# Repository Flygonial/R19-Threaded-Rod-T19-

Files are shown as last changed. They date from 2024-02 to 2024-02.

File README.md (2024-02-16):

# R19-Threaded-Rod-T19-

The repository for all the source files, code, and .stls for my threaded rod derivative of the T19, the R19. Held together with three 1' 8-32 threaded rods, and assorted 6-32 bolts (you also can use M3, but it is a bit hacky), and also aesthetically distinct. The cage has been changed to feature a threaded rod adapter (recommend 100% infill) and space for a rod overhead, the magwell has been adapted to accept these same rods and had its controller covers redesigned, and the rear end has been entirely remodeled (but still adhering to the original blaster's design language). 

Designed for a generic Amazon 40x60mm [perfboard](https://www.amazon.com/ELEGOO-Prototype-Soldering-Compatible-Arduino/dp/B072Z7Y19F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), the rear end of the blaster has been narrowed to more closely adhere to the stepper's profile. Ironically, this does slash half-length compatibility since that variant of the T19 kept its ESCs in the Drive Housing. I bought my own Arduino Pro Minis and DRV8855 boards and followed Toruk's [detailed but somewhat outdated guide](https://torukmakto4.blogspot.com/2019/01/t19-build-guide-part-7-blaster.html). Do note that pins 2 & 3 were reassigned to the tachometer lines [which need to be exposed from under your ESC's shrink wrap and hot-wired to](https://torukmakto4.blogspot.com/2021/01/flashing-ztw-spiders-for-flyshot.html), and correspond to now separate throttle lines for each ESC (10 & 2 and 9 & 3 respectively). As far as pin changes, note that I ended up reassigning the STEP pin off the DRV8855 to A0 (D14) and its DIR pin to A1 (D15). As the trigger lines follow the original guide (at 11 & 12), those were changed as well. I changed register accesses to correspond to these as well, which are documented in my code.

* D11: PORTB 00001000 - Trigger line 1
* D12: PORTB 00010000 - Trigger line 2
* D14: PORTC 00000001 - STEP signal
* D15: PORTC 00000010 - DIR signal

All code related to driving select-fire or speed/ROF setting were commented out. Implementing an old-styled hold down trigger on boot to set velocity and/or a tournament lock wire are things I'm interested in but that's the way it is now. If working from the original T19 source, or using mine, do be a bit more careful than me and not change/comment out things you actually needed. Bregg's [fork](https://github.com/MatthewBregg/SimpleT19Code) may be more useful for you if you want to work from scratch with your own hand-wired board and pinouts, and if you don't plan on implementing on-the-fly velocity and ROF tuning or select-fire.

To assemble the stock, keep in mind that you will need to cut 1/2"x1/8" aluminum flatbar to 200mm, trace out the drill holes (insert into the stock and mark drill points), and then cut out the locking points yourself. These can be configured to your liking, but I don't recommend making any points beyond about 150mm (which is already about 12" LOP) down as there will no longer be adequate support for bar contact to the stock. For each slot, measure out about 6mm in length for a slot and use a triangular file to open up each side and a flat file (with its thinner side) to finish it off. You can get away with as little as about 3mm deep, just don't make it too deep and compromise the flatbar's structural integrity. The locking pin is held in place by a piece on the end of the stock and needs its own spring.

I used the eBay Helibatics F-30A (originally Hobbyking) clones for 30A SimonK ESCs. I'm not positive this will be a reliable source forever (probably not), but the seller is a responsive, nice guy who has a big stockpile of them, and these ESCs are known to be fairly fuss-free for being flashed with FlyShot. I used the Arduino method in MBregg's earlier linked post, where I used KKMultiCopter, picked arduinosblinker inside the software, hooked my ESC up to a power supply (NiMH pack, Lipo, anything with enough voltage and some baselin of current capability works), and flashed Toruk's pre-compiled bs_nfet.hex file. Without buying an extra tool or needing to deal with Windows' shoddy USB driver compatibility, this worked and all I needed to do was install Java (and promptly uninstall it afterward).

With all this being said and done, keep in mind that this is primarily meant as a one-off build for myself. It has hacky, janky bits and will not be well-documented. Additional desired features, like short support, select-fire support, etc., are not likely to be implemented unless I want them for myself. I am open to answering questions on snags I faced and how these can be addressed, but no promises.`

# Licensed under the Creative Commons BY-SA 4.0 license
Inherited from the license of the T19, developed by torukmakto4. Information here: https://creativecommons.org/licenses/by-sa/4.0/

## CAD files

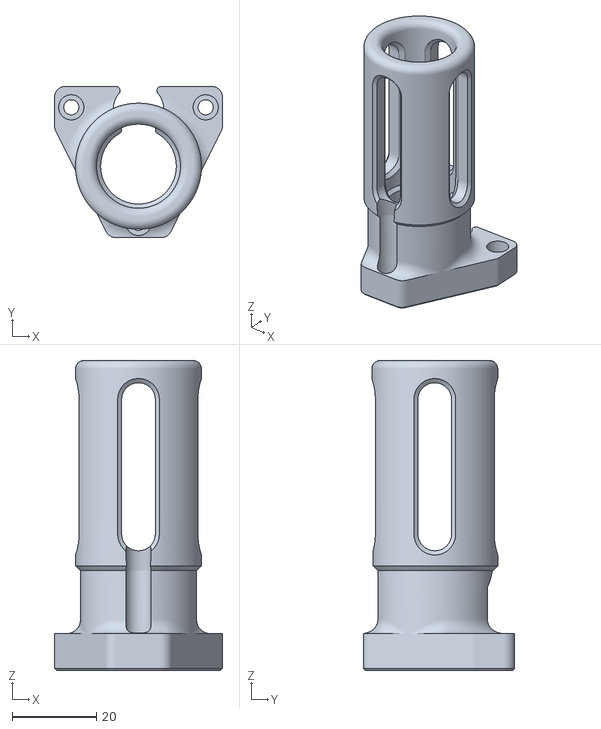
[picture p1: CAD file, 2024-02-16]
Cage/R19 Flash Hider.stl
40.0 x 36.0 x 73.8

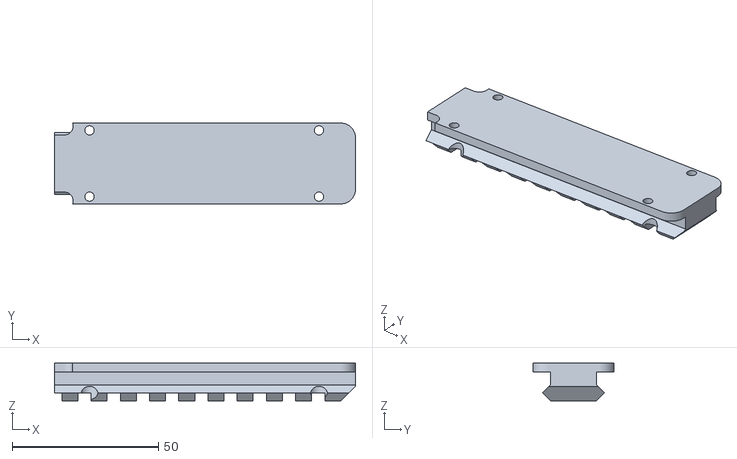
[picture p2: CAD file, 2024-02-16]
Drive/R19 Drive Rail.stl
103.0 x 27.7 x 13.0

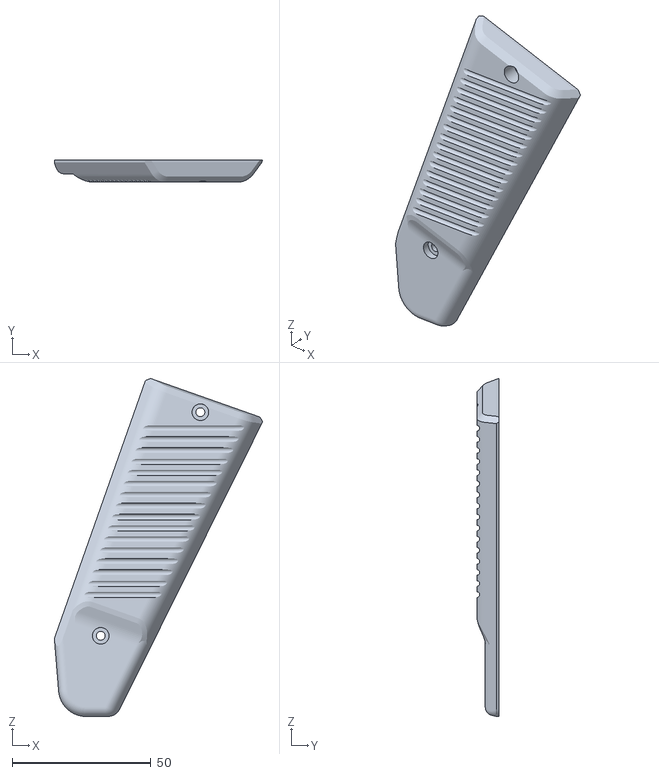
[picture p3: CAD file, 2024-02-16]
Grip/Right Grip Panel.stl
75.1 x 8.00 x 121.9

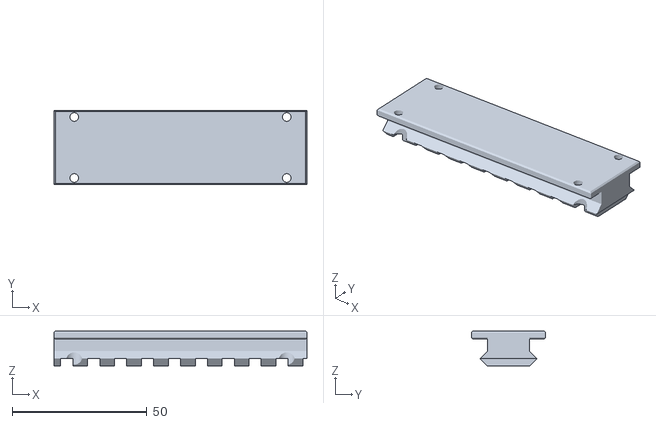
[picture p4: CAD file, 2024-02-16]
Magwell/R19 FL Rail.stl
94.0 x 27.7 x 13.0

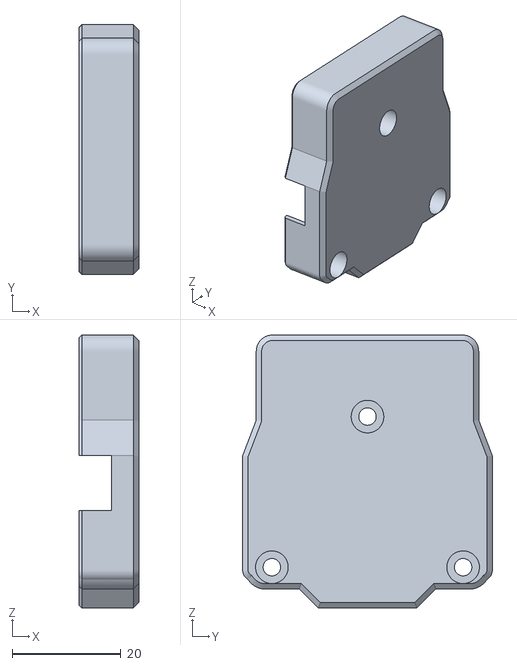
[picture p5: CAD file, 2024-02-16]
Stock/Locking Pin Cover.stl
11.0 x 45.9 x 50.2

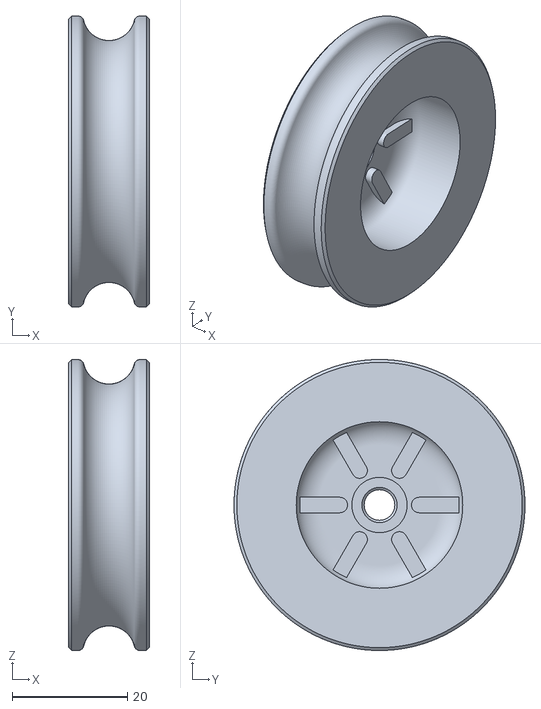
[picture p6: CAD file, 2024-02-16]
Cage/Hy-Con_Wheels_iFlight_XE_2207_PRO_9.5mm.stl
14.0 x 50.5 x 50.5

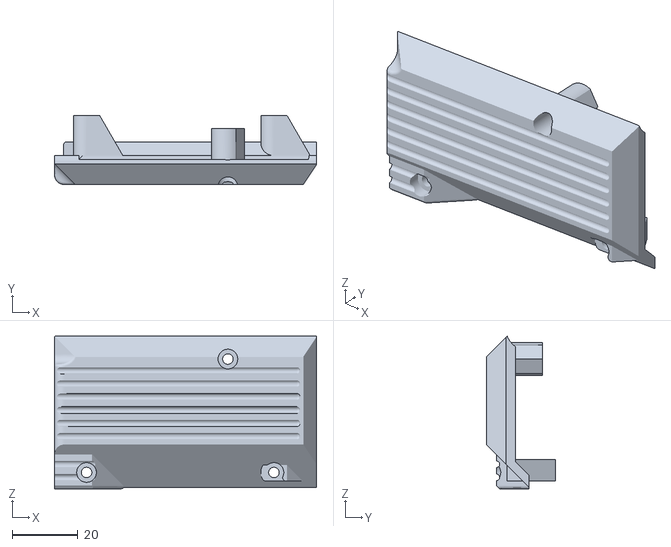
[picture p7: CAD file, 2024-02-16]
Magwell/R19 Right Controller Cover.stl
79.7 x 21.0 x 46.5

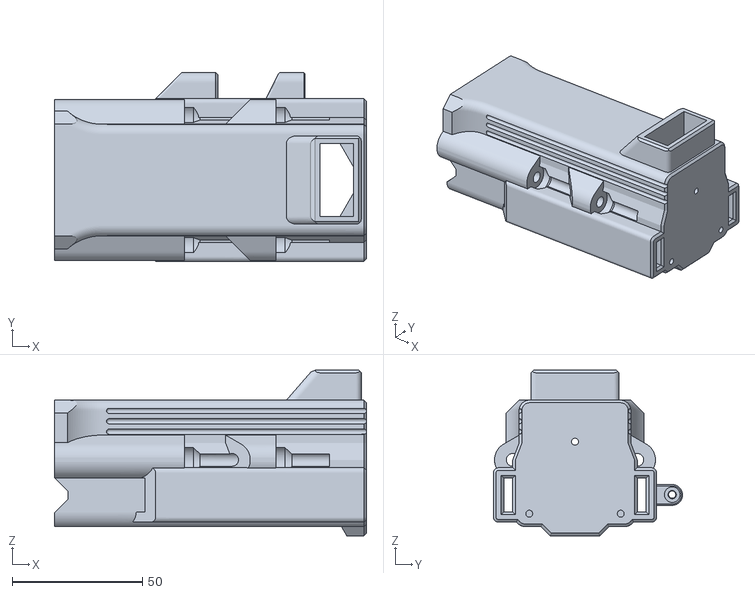
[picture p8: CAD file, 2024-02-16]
Stock/R19 Battery Stock.stl
120.0 x 72.8 x 63.7

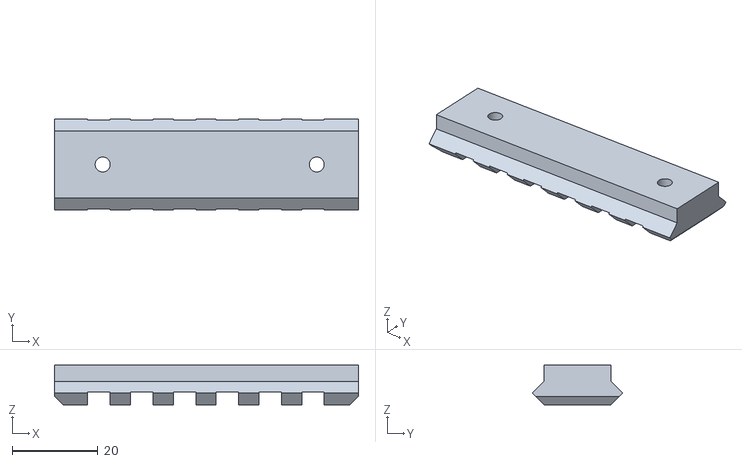
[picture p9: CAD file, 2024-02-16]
Cage/T19DeltaSideRail.stl
71.0 x 21.2 x 9.32

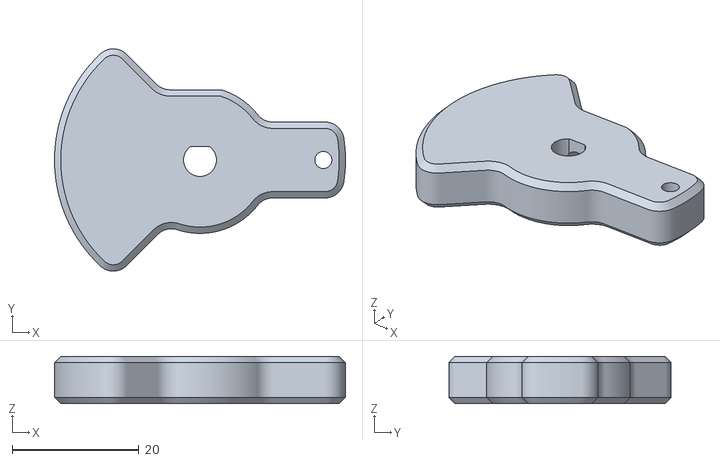
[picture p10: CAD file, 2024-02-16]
Drive/R19 Crank.stl
46.0 x 35.1 x 7.50

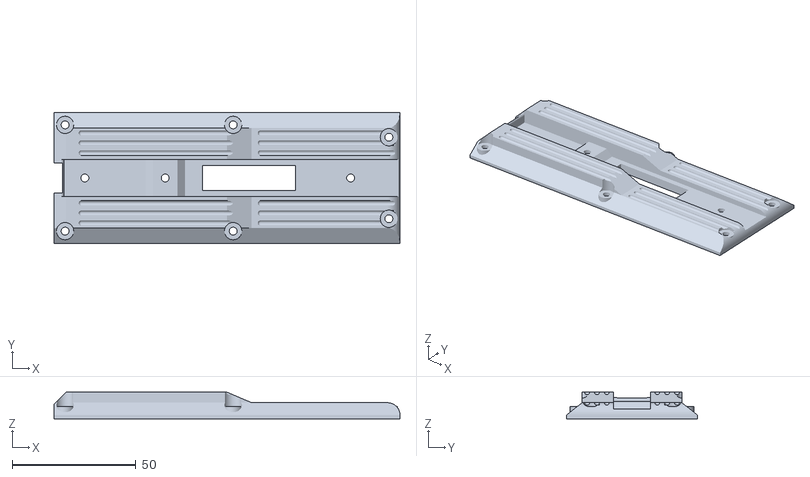
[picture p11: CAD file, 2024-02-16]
Grip/Grip Plate.stl
140.0 x 53.0 x 10.8

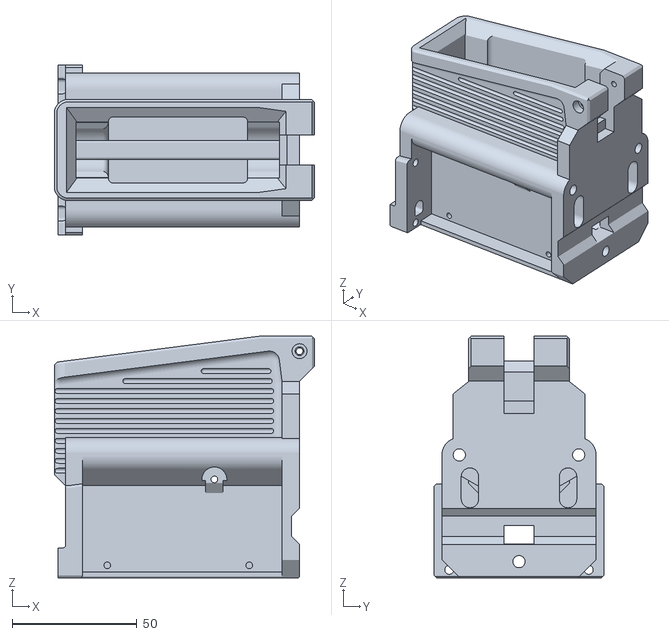
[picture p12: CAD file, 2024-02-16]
Magwell/R19 Magwell.stl
104.4 x 68.4 x 97.0

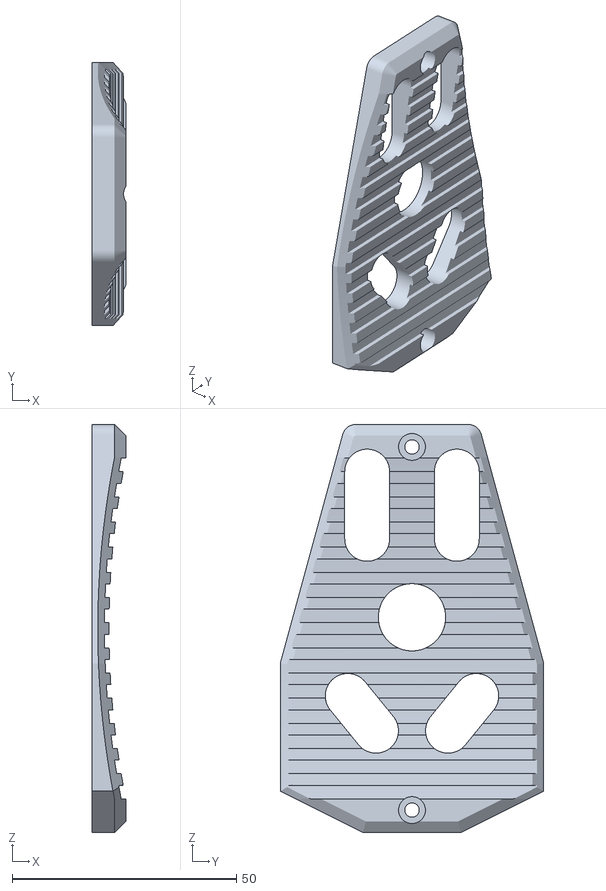
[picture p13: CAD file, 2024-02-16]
Stock/R19 Stock Pad.stl
7.50 x 58.8 x 91.0

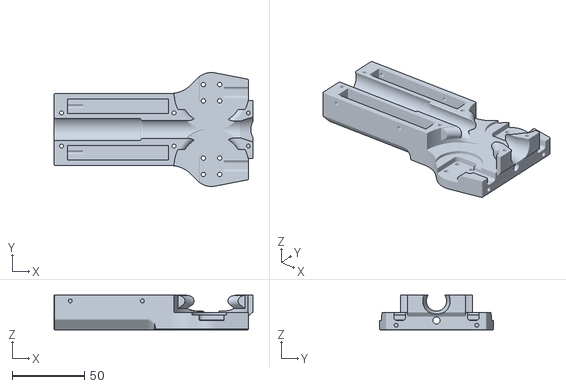
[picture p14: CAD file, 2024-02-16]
Cage/R19 9.0 Hy-Con Delta Cage.stl
138.0 x 79.0 x 24.0

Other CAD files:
Grip/Left Grip Panel.stl
Drive/R19 Drive Housing.stl
Grip/R19 Grip Frame.stl
Magwell/R19 2Way Release.stl
Cage/Hy-Con_Wheels_iFlight_XE_2207_PRO_9.0mm.stl
Cage/HyCon Delta BR2207.stl
Cage/R19 Cage Adaptor.stl
Cage/R19 Delta Cage Rail.stl
Cage/R19 Underrail.stl
Cage/Side Rail Delete.stl
Drive/BoltBushing.stl
Drive/R19 Bolt.stl
Drive/R19 Drive Cover.stl
Drive/R19 Drive Spacer.stl
Grip/R19 Trigger Cover.stl
Grip/R19 Trigger.stl
Magwell/R19 Left Controller Cover.stl
Magwell/T19FLRelease.stl
Source/HyConiFlightXE2207PRO Source.f3d
Stock/Flatbar Locking Pin.stl
Stock/R19 Buttplate.stl
Stock/R19 Tray Door.stl

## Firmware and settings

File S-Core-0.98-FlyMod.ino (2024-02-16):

 ////S-Core Blaster Controller Firmware
 ////Version 0.98
 ////by torukmakto4
 ////DZ Industries
 ////This is part of Project T19
 ////Forever Open - Forever Independent
 ////Project T19 and this Software (DZ Core) are released under the Creative Commons BY-SA 4.0 license.
 ////https://creativecommons.org/licenses/by-sa/4.0/
 ////This is free and open source software.
 ////You may use or modify it for any purpose. No warranty or guarantee of fitness for any purpose is provided.
 ////It may be included in a product for sale, given that attribution is provided,
 ////and that if altered, the modified source is made publically available in a very clear manner.
 ////ANY DERIVATIVE OF THIS PRODUCT MUST BE PUBLISHED UNDER THE ORIGINAL LICENSE.
 ////No attempt to circumvent/thwart access or obfuscate its release by any technical measure may be made.
 ////In the end:
 ////Please arms race responsibly,
 ////don't be greedy,
 ////and respect the sporting spirit of our great hobby,
 ////above all else.
 ////DBAD.
 
 ////This targets:
 ////S-Core Single-Board Blaster Manager 1.0/1.5
 
 ////Flash this as (in Arduino IDE): Arduino Pro Mini 5V/16MHz.
 ////Use "Upload using programmer" (Shift-Upload) using a ISP tool and the 6-pin header on the S-Core board. Serial Bootloader flashing is NOT supported on S-Core.
 
 ////General blaster assumptions:
 ////200s/rev (100 pole) 2 phase hybrid stepper
 ////direct drive scotch yoke bolt, 1 shot per rev 
 ////SPST bolt limit switch
 ////SPDT trigger switch. Common to ground. Inputs are 1k pullup.
 ////Selector should be 3 position center off SPDT. Common to ground, position 1 and 2 to input lines (1k pullup)
 ////User Analog Input: Connect to wiper of a potentiometer, end terminals 5V and ground.
 ////SpeedLock input: This is a pot directly on the board.
 
 ////ATmega328P @ 16MHz with external ceramic resonator
 
 ////PINOUTS - S-Core 1.0/1.5
 //AVR pin - Arduino IDE pin - functionality
 //PC0 - D14 - Solenoid driver. Output. Active high. Pulldown (S-Core 1.0) - It is a GPIO pin on the 1.5.
 //PC1 - D15 or A1 (ADC capable) - Exposed on the GPIO connector for expansion or arbitrary use.

 // No selector switch on mine, remove and reassign:
 //PC2 - D16 - Selector input 2. Pullup.
 //PC3 - D17 - Selector input 1. Pullup.

 // Changed Stepper pins:
 // OLD:
  //PC4 - D18 - DRV8825 Step signal. Output. Rising edge triggered.
  //PC5 - D19 - DRV8825 Direction signal. Output.
 // NEW: PC0 and PC1
  //PC0 - D14 (A0) - DRV8825 Step signal, output, rising edge triggered.
  //PC1 - D15 (A1) - DRV8825 Direction signal. Output.

// This matches the original T19 wiring with the perfboard and uses the selector switch pins:
// NEW:
 //PB3 - D11 - Trigger input 1. Pullup.
 //PB4 - D12 - Trigger input 2. Pullup.
// OLD:
 //PD0 - D0 - Trigger input 1. Pullup.
 //PD1 - D1 - Trigger input 2. Pullup.

 //PD2 - D2 - INT0 - Tach input channel 0 (M1F). (Warning: These should NOT be allowed to float with the interrupt turned on if unused!!!!!!)
 //PD3 - D3 - INT1 - Tach input channel 1 (M2F).
 //PD4 - D4 - Bolt limit switch input. Pullup.
 //PD5 - D5 - DRV8825 M2. Output
 //PD6 - D6 - DRV8825 M1. Output
 //PD7 - D7 - DRV8825 M0. Output
 //PB2 - D10 - OCR1B - Throttle channel 0 (M1, M1F) associated with INT0 (PD2)
 //PB1 - D9 - OCR1A - Throttle channel 1 (M2, M2F) associated with INT1 (PD3)
 //PB0 - DRV8825 Enable. Output. Active low.
 //ADC6 - User analog input (KNOB)
 //ADC7 - Onboard analog input pot (SPL)
 
 //ICSP header:
 //PB3 - MOSI
 //PB4 - MISO
 //PB5 - SCK
 //PC6 - RESET (pullup)
 
 //PB6/PB7 - XTAL1/2 (Abracon Ceramic Resonator is present)
 
 //VCC = AVCC = AREF = 5V

 ////changelog of the NEW new era:
 ////08-19-19 - Rework for S-Core board, add dual-channel throttle and tach-based STC. Remove delay-based STC.
 ////08-31-19 - Implement digital governor updates, selective profile, analog speed inputs, ...
 ////12-30-19 - WIP Remove Alternate Mode. Analog knob is bolt speed control in run mode. Trigger down at boot to set speed.
 ////           Default to SPL setting. Throttle PWM interrupt to overlay governor updates instead of bitbang.
 ////           Add restart compensation to improve followup shot snappiness.
 ////           And then promptly comment out restart compensation. 
 ////02-09-20 - Fix all the wrong stuff with governor update interrupt management
 ////           Add ROF linearization, provision for configuring ROF in RPM, etc.
 ////           Start improving selftest
 ////02-14-20 - New hardware selftest, velocity watchdog, and fault codes
 ////02-29-20 - Rework selftest a bit to help bolt reset procedure spit out jam debris automatically with the flywheels and not create any new stoppage by feeding unknowingly while homing
 ////           Make Orthomatic feed control stricter and use a more appropriate polling period for checking tachs.
 ////04-07-20 - Fix erroneous trigger disconnection while full auto and decelerateBoltToSwitch(), etc.
 ////11-01-20 - Save user flywheel speed to EEPROM
 ////12-06-20 - Improve license statement clarity/intent (etc.)
 ////           Add quick "^beep^-_beep_" ("Old cellphone with dead battery") alarm feedback when a shot request
 ////           times out trying to reach set flywheel speed.
 ////           Disable tach interrupts as if the shot cycled when shutting down shots that timed out rather than erroneously leaving them on.
 ////           Make overspeed detect less strict (65 vs. 50) to prevent jumpy iflight cages from throwing errors.
 
 ////This uses the per-cycle lightweight calculation of stepper commutation period described in
 ////http://hwml.com/LeibRamp.pdf
 
#include <EEPROM.h>
 
////PWM Timer1 interrupt governor control variables
volatile int gov_currentBit;               //Loop counter/index (shall not be unsigned)
volatile unsigned long save_ocr1a;         //Save throttle settings to resume emitting them after all digital speed bits are shifted out
volatile unsigned long save_ocr1b;
volatile unsigned long governor;           //this has to be a volatile even though the ISR does not modify it
volatile boolean gov_enable_strobe = false; //Set to true to fire off update
volatile boolean gov_packet_active = false; //True while shifting bits out in the gov ISR, resets at the end of the cleanup cycle

int gov_update_repeats = 10;               //Number of min. times to repeat (Like Dshot commands, a one-time setting should be sent about 10 times to ensure noise robustness, etc.)

////FlyShot constant/setup section
volatile unsigned long gov_ocr_t0h = 26;   //T0H = 100us (Less than 250us)
volatile unsigned long gov_ocr_t1h = 90;   //T1H = 400us (More than 250 and less than MIN_RC_PULS)
//TL is by the PWM period. We will just keep running at 400Hz.
  
////tach variables - modified in tach ISRs
////tach pulse is counted on rising edge, once per AC cycle: 6*TIMING_MAX/4
////speed range should be something like 1200us - 330us for 7100 - 25900 motor rpm for reference
volatile unsigned long thisPulseTime0;
volatile unsigned long lastPulseTime0;
volatile unsigned long pulseLength0;
volatile unsigned long thisPulseTime1;
volatile unsigned long lastPulseTime1;
volatile unsigned long pulseLength1;

////tach watchdog variables
volatile boolean drive0TachValid = false;  //Make sure we received fresh data before acting on it
volatile boolean drive1TachValid = false;

////Orthomatic - Tach based STC variables.
volatile unsigned long speedSetpoint;     //us (6 * TIMING_MAX / 4)
int goodTachsToFire = 5;                  //how many consecutive good readings to consider motors to be stable and start bolt motion?
unsigned long speedOffsetMargin;          //Consider tach in range if speedOffsetMargin us greater than (lower speed) speedSetpoint
unsigned long speedOffsetMarginMin = 45;  //At low speed   (This compensates competing effects from period being 1/f, control loop performance, and tach resolution so isn't much more
unsigned long speedOffsetMarginMax = 22;  //At max speed    than a fudge factor)
int goodTachCount = 0;                    //counter for loops with good speed reading
unsigned long startBlankTime  = 1;        //actually delay step for tach checks
unsigned long failTime = 1000;            //Abort if drives don't either send tach pulses or reach set speed in a reasonable time.
unsigned long lastTriggerDown;            //(ms) time trigger pulled

////Speed/Analog control variables.
unsigned long knobValueRaw;
unsigned long knobValue;                  //10 bit ADC input for user knob
unsigned long splValueRaw;
unsigned long splValue;                   //10 bit ADC for SPL pot on board - Tournament lock
unsigned long minROF = 300;               //In rounds per minute (or pusher motor RPM)
unsigned long maxROF = 860;               //In rounds per minute (or pusher motor RPM) (Note this should be, at most, close but slightly higher to what runSpeedMax below enforces)
unsigned long setpointROF;                //To store set ROF input
unsigned long minRPM = 5000;              //Fly speed command min (Set this appropriately for your system to ensure passing darts at minimum speed)
unsigned long maxRPM = 25510;             //Fly speed command max (Set this appropriately. If the drive can't actually reach this speed you won't be able to fire!)
unsigned long limitRPM;                   //Speed limit (Tournament lock) - this potentiometer should be inaccessible without tools
unsigned long setpointRPM;                //Set RPM
unsigned long setpointGovernor;           //Convert RPM to governor (8 * TIMING_MAX)
unsigned long motorPolepairs = 7;         //Pole order of your flywheel motors

// Debugging variables for self-test prints:

/*
int flag0 = 0;
int flag1 = 0;
int flag2 = 0;
int flag3 = 0;
*/

//Profile/Selector stuff.
int selector = 0;
int selectorLast;                         //Save selector state. This should remain at the same as the above unless a change happened.
boolean isBurst = false;                  //Global enable/disable Burst Length Limitation (Software Trigger Disconnector)
int burst = 0;                            //Current burst length - Load this with a number of shots to fire before firing if isBurst is 1
int burstCounter;                         //Counter

//Off-Cycle busywork flip flop scheduler.
boolean OffCycleState = true;             //Change state on every idle loop (NOT firing).
                                          //Not all busywork tasks (such as ROF and selector updates) need be performed every cycle.
                                          //Split the busywork tasks in 2 so we're not blocked too long when we're supposed be paying close attention to the trigger.

//Selector config - Defaults here are full auto, 2 round burst, semi.
int bursts[3] = {0, 2, 1};                  //Burst lengths - Every index that is true in the below must have a corresponding nonzero number in this.
boolean isBursts[3] = {false, true, true};  //Disconnector mask.

//BOLT DRIVE PARAMETERS - don't mess with these unless you know what you are doing
unsigned long startSpeed = 400; //us (default 400 - leave alone)
unsigned long shiftSpeed = 150; //us (default 150)
unsigned long runSpeed;         //us (Fed from analog input logic)
// unsigned long runSpeedMax = 88; //Bolt speed absolute maximum - limit precisely
unsigned long runSpeedMax = 75000/(840 /* Rounds Per minute */); //Bolt speed absolute maximum - limit precisely
double accelPhaseOne = 0.000000253494; //m value for ramp in low speed region
double accelPhaseTwo = 0.000000180748; //m value for ramp in high speed region
double decel =         0.000000439063; //m value for hard decel
int boltShutdownTime = 1000; //ms - post-shot delay after which motor current is turned off
 
//fire control state variables section
boolean prevTrigState = 0;
boolean currTrigState = 0;
unsigned long lastTriggerUp = 0;
int stepsToGo;
boolean firstRun = 1;
boolean boltHomed = 0;
double currSpeed = startSpeed; //to be used by fire() to be aware of motor speed from last run and mate speed ramp to that
double stepdelay; //us

//Selftest counters
int selftestStepCounter = 0;
int selftestCycleCounter = 0;
int selftestGrowlCounter = 0;  //For internal use stepper_code_blipper
int selftestAlarmCounter = 0;  //For internal use stepper_alarm

//Motor drive selftest stuff
unsigned long selftestTachIntegPollTime   = 300;  //us - delay step for monitoring state of tach lines at idle to hopefully catch swings
int           selftestTachIntegCheckCount = 10;   //Number of matching logic states above time apart to determine stable
int           selftestTachIntegChecks;            //Counter
boolean       selftestTachState;                  //Save logic state of first read
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
void loop(){
  if(firstRun) {
    //Wait for SimonK boot and arm (TBD value, Selftest already waits 500ms)
    delay(500);
    //Do POST
    selftest();
    //Wait a moment and...
    delay(500);
    //catch trigger down at boot - Enter user speed configuration mode
    if(digitalRead(11) && !digitalRead(12)) {
      //enable both flywheel drives
      OCR1B = 500;
      OCR1A = 500;
      delay(100); //ensure throttle validity during motor start "stop-quickly" logic in SimonK
      //trap trigger down state in this loop:
      while(digitalRead(11) && !digitalRead(12)) {
        //leave flywheel drives spinning, and continuously do governor updates from the analog knob
        updateSpeed(); //Nb: updateGovernorBoth blocks while a packet is being transmitted, thus so does this call.
      }
      //trigger release exits trap (leaving last speed configuration in place) to HERE.
      //Speed is now set on the motor drives AND the tach control variables to match
      //Nb: Motors are stll enabled. That's OK as speedtrap() will shut them down.
    } else {
      //default speed is tournament lock setting
      delay(100); //Some anti-noise buffer
      while(gov_update_repeats) {
        updateSpeedFixed(); //Nb: updateGovernorBoth blocks while a packet is being transmitted, thus so does this call.
        delay(20); //Some anti-noise buffer
        gov_update_repeats--;
      }
      delay(100); //Same here
    }
    ////Speed setpoint and associated parameters fed to STC stuff is now set in concrete for the remainder of this uptime.
    //Verify set speed. Nb: Since this happens seamlessly after user-adjusting speed (the motors were still running) there is no "blip"
    speedtrap();                 //Bust any wrong flywheel speeds now before firing is allowed. Starts motors if they weren't already and shuts them down afterward.
    //Fell through = Cleared for launch.
    //Initialize fire control and bolt speed
    // selector = 6;                //Illegal selector (Force updateSelector to do something, since the new selector value may be 0)
    // updateSelector();            //Configures disconnector enable and burst length per selector status and config
    runSpeed = runSpeedMax;      //Backup. This should NEVER be necessary. That value should be immediately clobbered by updateROF(). 
    updateROF();                 //Must set a bolt speed before firing.
    //clear flag
    firstRun = 0;
  }
  disableGovernorInterrupt();    //It shouldn't have been on - make very sure
  //initial debounce on trigger from idle state. Safety measure.
  prevTrigState = currTrigState;

  // CHANGED
  currTrigState = (digitalRead(11) && !digitalRead(12));
  if(currTrigState && prevTrigState){
    //turn motor current on
    digitalWrite(8, LOW);
    //enable tachs
    enableTachInterrupts();
    //start flywheels
    OCR1A = 500; //go
    OCR1B = 500; //go
    
    ////Speed feedback STC section.
    //This project went at one point by "Orthomatic".

    //Record trigger down event timestamp
    lastTriggerDown = millis();
    //Wait for both drives to have vaild tach. This effectively checks that they are actively toggling their tach lines. These flags are cleared before we get here,
    //so the only thing that would have turned them on is the tach ISR.
    while(!(drive0TachValid && drive1TachValid && ((millis() - lastTriggerDown) <= failTime))) {
      delay(1);
    }
    if((millis()-lastTriggerDown) >= failTime) {
      //Whoops. We exited the invalid-tach trap because one or more drives failed to produce any speed feedback in a reasonable time. Perhaps something got unplugged.
      //Disable tach:
      disableTachInterrupts();
      //Shut down drives:
      OCR1A = 230;
      OCR1B = 230;
      //Set pending NoTach alarm (Single Low beep).
      //Then trap trigger down state here. Require a trigger reset to reattempt.
      alarm_want = 1;

      // CHANGED
      while(digitalRead(11) && !digitalRead(12)) {delay(5);}
      goodTachCount = 0;
      lastTriggerUp = millis();
    } else {
      //We exited the invalid-tach trap because both tachs went valid. This is what's supposed to happen.
      //Wait for drives to reach speed and stay there for goodTachsToFire *consecutive* reads, and then fire. (0.95 - Robustness improvement)
      while((goodTachCount < goodTachsToFire) && ((millis() - lastTriggerDown) <= failTime)) {
        //Increment goodTachCount every time both speeds are in range, with poll cycle about as long as the target period (little longer in practice)
        if((pulseLength0 <= (speedSetpoint + speedOffsetMargin)) && (pulseLength1 <= (speedSetpoint + speedOffsetMargin))) {
          goodTachCount++;
        } else {
          goodTachCount = 0;                     //Strictly reject any out of range reads (This is in the range of 3-7 reads in a row we're looking for to fire so no sense in allowing "mulligans")
        }
        delayMicroseconds(speedSetpoint);        //Abuse target signal period as polling period
      }
      //We returned. But why? If it's a timeout, then goodTachCount will not have reached goodTachsToFire.
      if(goodTachCount < goodTachsToFire) {
        //Whoops. We exited because: Drives failed to reach speed setpoint in a reasonable time.
        //Disable tach:
        disableTachInterrupts();
        //Shut down drives:
        OCR1A = 230;
        OCR1B = 230;
        //Set pending SpeedFail alarm ("Dead phone"), then trap trigger down state here. Require a trigger reset to reattempt.
        alarm_want = 2;
        while(digitalRead(11) && !digitalRead(12)) {delay(1);}
        goodTachCount = 0;
        lastTriggerUp = millis();
      } else {
        //Successful acceleration: start firing.
        //First load the burst length to fire:
        if(isBurst) {burstCounter = burst;}
        //Already know speed is good at this point, mute tach ISRs
        disableTachInterrupts();
        fire();
        //first sealed-in shot is over. Check trigger *quickly* for downness (Nb: We may be commutating the pusher right now) and fire again if down and called for. Trigger is PD0, PD1.
        //This second fire() call may execute 0 times if isBurst is true and burstCounter starts as 1.
        // CHANGED
        while((!isBurst || --burstCounter > 0) && (PINB & 0b00001000) && !(PINB & 0b00010000)){
          fire();
        }
        //Here, firing is definitely OVER. Get the bolt back safely to home position (N.b.: Flywheel Drives are still enabled right now, so any spurious feed from this is safe)
        if(!decelerateBoltToSwitch()) {reverseBoltToSwitch();}
        //Reset tach cycle counter
        goodTachCount = 0;
        //Shut down drives only NOW:
        OCR1A = 230;
        OCR1B = 230;
        lastTriggerUp = millis(); //Not ACTUALLY trigger up any more due to the disconnector trap. A burst disconnect is a pseudo trigger up.
        //Main disconnector trap - This is where we land if firing ends and trigger is still down.
        //Note that if full auto, leaving this active would result in trigger events during the decel window trapping here, I don't know how I got along with that so long without catching it.
        if(isBurst) {while(digitalRead(11) && !digitalRead(12)) {delay(1);}}
      }
    }
  } else {
    //Trigger UP high priority loop tasks - keep wheel drives off, flag tachs as invalid, turn off bolt current after boltShutdownTime ms.
    OCR1A = 230; //shutdown
    OCR1B = 230; //shutdown
    goodTachCount = 0;
    drive0TachValid = false;
    drive1TachValid = false;
    if((millis() - lastTriggerUp)>boltShutdownTime){
      //Play any pending STC alarm and clear it, then turn bolt motor current off.
      if(alarm_want) {
        if(alarm_want == 1) {
          stepper_beep_low();
        } else {
          stepper_fast_alarm();
        }
        alarm_want = 0;
        delay(60);          //If motor was just beeping, wait for vibration to decay before unlocking
      }
      digitalWrite(8, HIGH);
    }
    
    //Trigger UP lower priority busyworks - Selector. ROF.
    /*
    if(OffCycleState == true) {
      updateROF();            //This triggers an ADC read and does some math so it is the slower of the two.
                              //It might be nicer to split up the ROF linearization and ADC read into 2 tasks.
      OffCycleState = false;
    } else {
      // updateSelector();       //Returns fast unless selector changed
      OffCycleState = true;
    }
    */
  }
}

////Tach ISRs, take input pulse length, stuff it into the corresponding variable and flag it as fresh.
////TBD: micros() needs to go away because the resolution is garbage (but functional). Probably going to use Timer2.
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
